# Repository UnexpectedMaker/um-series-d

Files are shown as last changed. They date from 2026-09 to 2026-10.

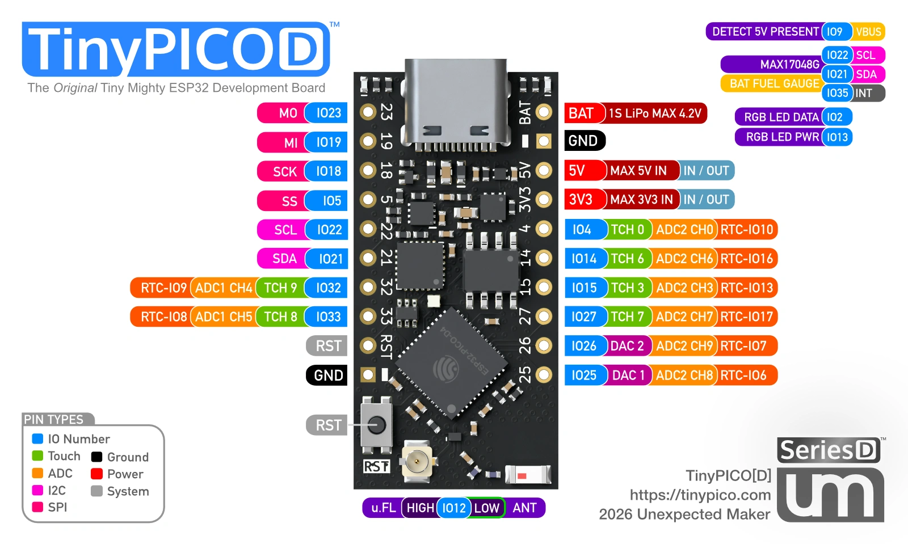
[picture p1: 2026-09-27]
pinout_cards/TinyPICOD_pinout.webp

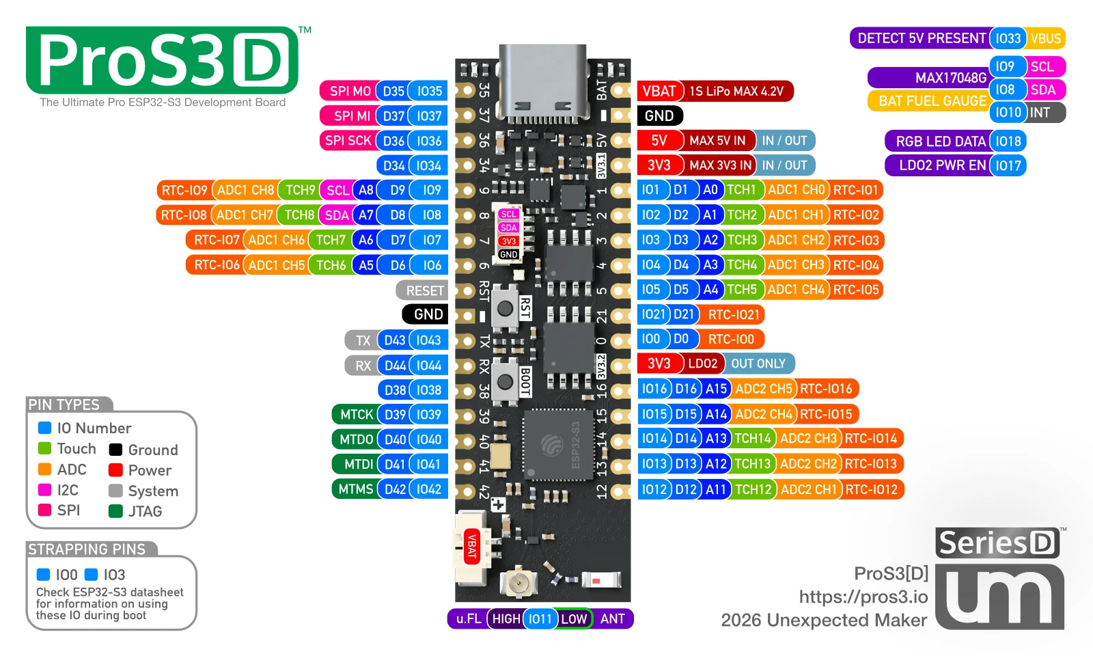
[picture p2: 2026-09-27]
pinout_cards/ProS3D_pinout.webp

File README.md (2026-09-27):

# Unexpected Maker - Series[D]



Assorted files for my Series[D] development boards - ESP32-S3, ESP32-PICO-D4 and ESP32-C6.













You can find out more about my boards at https://unexpectedmaker.com#series-d

# Contents
In this repo you'll find the following items:

## 3D Models
3D STEP files for each of the TinyS3[D], ProS3[D], FeatherS3[D], EdgeS3[D], TinyPICO[D] and TinyC6[D] boards

You'll also find a STEP file for the EdgeS3[D] Reference Carrier board and a STEP for the M.2 connector footprint with the EdgeS3[D] inserted to help line things up.

## Schematics
PDF Schematics for each of the TinyS3[D], ProS3[D], FeatherS3[D], EdgeS3[D], TinyPICO[D] and TinyC6[D] boards.

## Code
Helper libraries, examples and shipping files for Arduino, ESP-IDF, MicroPython and CircuitPython - see the [code folder](code/) for details.

## KiCAD (v9)
Symbol and Footprint for EdgeS3[D] and a project folder for the EdgeS3[D] Reference Carrier PCB.

## Pin Reference Cards
Hi-res pinout reference cards for each of the TinyS3[D], ProS3[D], FeatherS3[D], EdgeS3[D], TinyPICO[D] and TinyC6[D] boards

# Support Unexpected Maker
I love designing, making, and releasing projects and products that empower others to learn and build amazing things! I do it because I believe it’s important to share knowledge and give back to the community as many have done before me. It helps us all learn and grow.

Please consider supporting me by buying some of my products from:

https://unexpectedmaker.com/shop

Or by buying one of my products on tindie or Lectronz:

https://lectronz.com/stores/unexpectedmaker

Or by becoming a Patron:

https://www.patreon.com/unexpectedmaker

## Unexpected Maker
http://youtube.com/c/unexpectedmaker

http://twitter.com/unexpectedmaker

https://discord.gg/xAHpApP

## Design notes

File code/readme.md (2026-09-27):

# Code - Unexpected Maker - Series[D] Boards 
Code examples, shipping files and helper libraries for Series[D] boards - TinyS3[D], ProS3[D], FeatherS3[D], EdgeS3[D], TinyPICO[D] and TinyC6[D].

Currently includes:

## Arduino
Check the [arduino folder](arduino/) for a link to the Series[D] Helper library and example code for the Arduino IDE, to be installed via the library manager. The helper library supports all Series[D] boards, including TinyPICO[D] and TinyC6[D].

## ESP-IDF
The [esp-idf folder](esp-idf/) contains the `um_seriesd` helper component and an example project, for all Series[D] boards. Requires ESP-IDF v5.3 or later.

Set the target for your board (`esp32s3` for TinyS3[D], ProS3[D], FeatherS3[D] and EdgeS3[D], `esp32` for TinyPICO[D] and `esp32c6` for TinyC6[D]) with `idf.py set-target`, then select your board under `UM Series[D] Helper` in `idf.py menuconfig`.

On the TinyC6[D] the RF switch is on the FXL6408 IO expander (XIO0). `um_begin()` sets up the I2C bus and IO expander, and the `um_iox_*` functions give you access to the other IO expander pins.

## MicroPython
Series[D] support for all Series[D] boards is coming to MicroPython as new board variants - the PR has been submitted but not merged yet.

Until then, TinyS3[D], ProS3[D] and FeatherS3[D] can use the original TinyS3, ProS3 and FeatherS3 builds available at [micropython.org](https://micropython.org/download/?vendor=Unexpected%20Maker).

Helper libraries and example code will be available soon.

## CircuitPython
Shipping files include the CircuitPython helper library and `code.py` for each board, plus a `lib` folder populated with the requirements for the `Adafruit MAX17048` Battery FG IC library.

Shipping files are available for TinyS3[D], ProS3[D], FeatherS3[D], EdgeS3[D], TinyPICO[D] and TinyC6[D]. The TinyC6[D] and EdgeS3[D] `lib` folders also include `fxl6408.py` for their IO expander (on the TinyC6[D] the RF switch is on XIO0, on the EdgeS3[D] XIO0-XIO7 are available as `edges3d.io_expander`), and the TinyPICO[D] `lib` folder includes `neopixel`, as the TinyPICO build doesn't have it built in.

CircuitPython support for EdgeS3[D] (that the EdgeS3[D] ships with) has been PR'd and merged into the CircuitPython repo.

There are no Series[D] board specific CircuitPython builds for TinyS3[D], ProS3[D], FeatherS3[D], TinyPICO[D] and TinyC6[D] - They use their original non Series[D] board CircuitPython builds.

Due to this, not every IO used on a Series[D] board is available in the `board` import, but all IO can be accessed using `microcontroller.pin`, for example, to access IO11 on the ProS3 build running on the ProS3[D], you use the following syntax:

``` python
# Setup the RF switch pin
ant_selection = DigitalInOut(microcontroller.pin.GPIO11)
ant_selection.direction = Direction.OUTPUT
```

## PlatformIO
The Arduino helper library can also be used with PlatformIO, see the platformio platform information at https://unexpectedmaker.com/develop.php?platform=platformio#platformio-setup

You can find out more about my Series[D] boards at https://unexpectedmaker.com#series-d

Please refer to the included license.

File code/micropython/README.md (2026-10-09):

# UM Series[D] MicroPython firmware - 2026-10-05

Series[D] support for MicroPython is current in a PR waiting for merge and inclusion in the next MicroPython release, so while we wait for that, I have provided firmware here built against IDF5.5.5 and the last MP main ranch as at October 5, 2026

Each `.bin` is the full merged image (bootloader + partition table + app).
Replace `PORT` with your serial port, e.g. `/dev/cu.usbmodem101`.

Erase first, then write.
Instrucitons below use esptool v5.

## ESP32-S3 boards (offset 0x0)

Download mode: hold BOOT, press and release RESET, release BOOT.

### TinyS3[D]
    esptool --chip  esp32s3 --port PORT erase-flash
    esptool --chip  esp32s3 --port PORT write-flash 0x0 UM_TINYS3D.bin

### ProS3[D]
    esptool --chip  esp32s3 --port PORT erase-flash
    esptool --chip  esp32s3 --port PORT write-flash 0x0 UM_PROS3D.bin

### FeatherS3[D]
    esptool --chip  esp32s3 --port PORT erase-flash
    esptool --chip  esp32s3 --port PORT write-flash 0x0 UM_FEATHERS3D.bin

### EdgeS3[D]
    esptool --chip  esp32s3 --port PORT erase-flash
    esptool --chip  esp32s3 --port PORT write-flash 0x0 UM_EDGES3D.bin

## ESP32-C6 boards (offset 0x0)

Download mode: hold BOOT while connecting USB.
These boards stay in the bootloader after flashing - press RESET to start.

### TinyC6[D]
    esptool --chip esp32c6 --port PORT  erase-flash
    esptool --chip esp32c6 --port PORT  write-flash 0x0 UM_TINYC6D.bin

## ESP32 boards (offset 0x1000)

### TinyPICO[D]
    esptool --chip esp32 --port PORT erase-flash
    esptool --chip esp32 --port PORT write-flash 0x0x1000 UM_TINYPICOD.bin

## Examples

The `examples` folder has a `main.py` for each Series[D] board. Each one uses the board's helper module (`tinys3d`, `pros3d`, `feathers3d`, `edges3d`, `tinyc6d` or `tinypicod`), which is built into the firmware above.

TinyC6[D] and TinyPICO[D] ship with MicroPython, so their `main.py` is the shipping code. TinyS3[D], ProS3[D], FeatherS3[D] and EdgeS3[D] ship with CircuitPython, so theirs are examples for when you put MicroPython on them.

Every example prints a hello, memory and flash info, and what's on the I2C bus, then cycles the RGB LED through a rainbow and prints the battery voltage and charge every 2 seconds. The TinyC6[D] and EdgeS3[D] also print the FXL6408 IO expander device ID.

The EdgeS3[D] has no RGB LED, so its example does the same without the rainbow.

To use one, copy it to your board as `main.py` and it will run at boot, for example:

`mpremote cp main.py :main.py`

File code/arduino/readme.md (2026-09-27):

# Unexpected Maker Series[D] Arduino Helper Library

This is the [helper library](https://github.com/UnexpectedMaker/seriesd_arduino_helper) for all the Unexpected Maker [Series[D] boards](https://unexpectedmaker.com/#series-d) - TinyS3[D], ProS3[D], FeatherS3[D], EdgeS3[D], TinyPICO[D] and TinyC6[D]. It can be used in the Arduino IDE or PlatformIO.

Examples can be found in the [examples directory](https://github.com/UnexpectedMaker/seriesd_arduino_helper/tree/main/examples), these can also be loaded from the examples menu in the Arduino IDE.

Examples include switching antenna output, reading the battery, controlling the RGB LED (if one is present on the board) and reading the light sensor (FeatherS3[D]).

## Selecting your Series[D] board

Apart from the EdgeS3[D], the Series[D] boards don't have their own [D] board listing in the Arduino boards list. Select the original board instead:

| Series[D] board | Board to select |
|---|---|
| TinyS3[D] | UM TinyS3 |
| ProS3[D] | UM PROS3 |
| FeatherS3[D] | UM FeatherS3 |
| TinyPICO[D] | UM TinyPICO |
| TinyC6[D] | UM TinyC6 |
| EdgeS3[D] | UM EdgeS3[D] |

## Installation

Please download the library called `UM SeriesD Helper` via the Arduino Library Manager.

## List of functions

```c++

// Initializes all UM Series[D] board peripherals
void begin();

// Set LDO2 on or off
// Only available on the ProS3[D] and FeatherS3[D] 
void setLDO2Power(bool on);

// Set RGB LED power on or off (On ProS3[D] and FeatherS3[D] it sets LDO2 on)
// Not available on the EdgeS3[D] 
void setPixelPower(bool on);

// Set RGB LED color
// Not available on the EdgeS3[D] 
void setPixelColor(uint8_t r, uint8_t g, uint8_t b);
void setPixelColor(uint32_t rgb);

// Set RGB LED brightness
// Not available on the EdgeS3[D] 
void setPixelBrightness(uint8_t brightness);

// Pack r,g,b (0-255) into a 32bit rgb color
static uint32_t color(uint8_t r, uint8_t g, uint8_t b);

// Convert a color wheel angle (0-255) to a 32bit rgb color
static uint32_t colorWheel(uint8_t pos);

// Set the blue LED on or off
// Only available on the FeatherS3[D]
void setBlueLED(bool on);

// Get the light sensor in volts (0-3.3)
// Only available on the FeatherS3[D]
float getLightSensorVoltage();

// Toggle the blue LED
// Only available on the FeatherS3[D]
void toggleBlueLED();

// Get the battery voltage in volts
// This function gets the voltage from the MAX17048
float getBatteryVoltage();

// Detect if VBUS (USB power) is present
// Not available on the EdgeS3[D] 
bool getVbusPresent();

// Set the RF Switch to external antenna
// On the TinyC6[D] the RF Switch is on the FXL6408 IO expander (XIO0)
void setAntennaExternal(bool state);

// FXL6408 IO expander (uses the TwoWire passed to FG_setup, or Wire if begin() is called first)
// Only available on the TinyC6[D]
bool IOX_begin();
void IOX_pinMode(uint8_t pin, uint8_t mode);
void IOX_digitalWrite(uint8_t pin, bool state);
bool IOX_digitalRead(uint8_t pin);
```

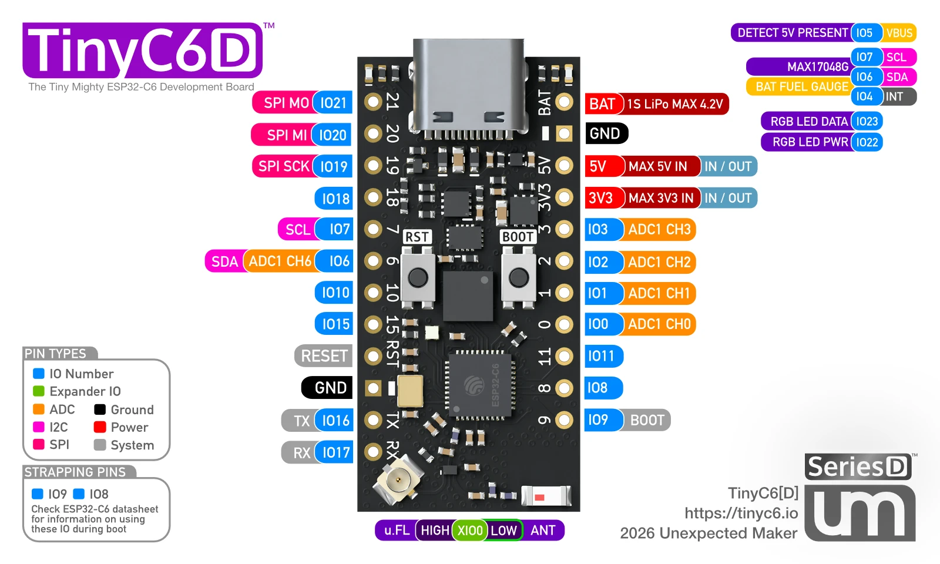
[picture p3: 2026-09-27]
pinout_cards/TinyC6D_pinout.webp

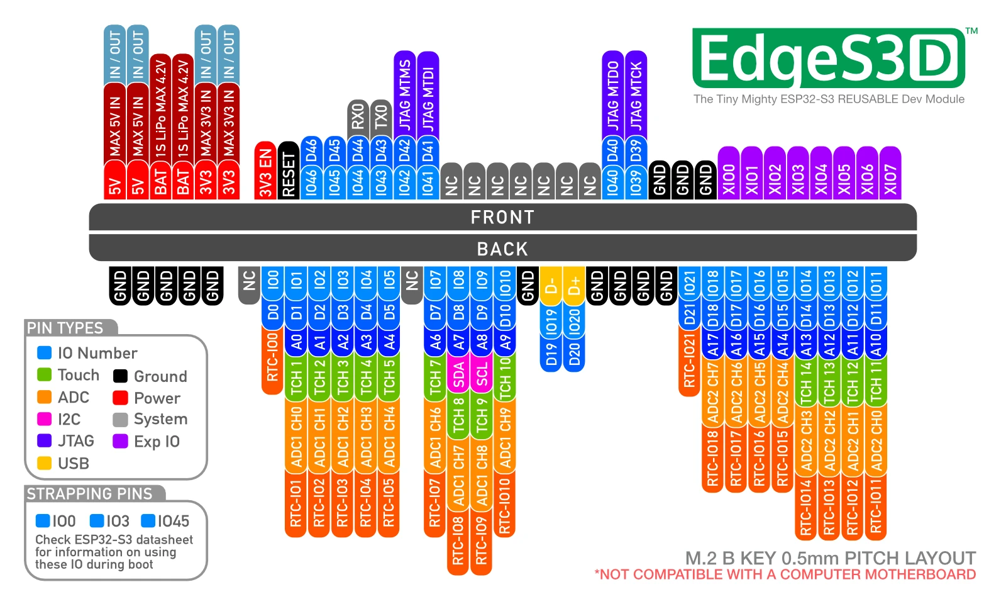
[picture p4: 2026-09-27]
pinout_cards/EdgeS3D_pinout.webp

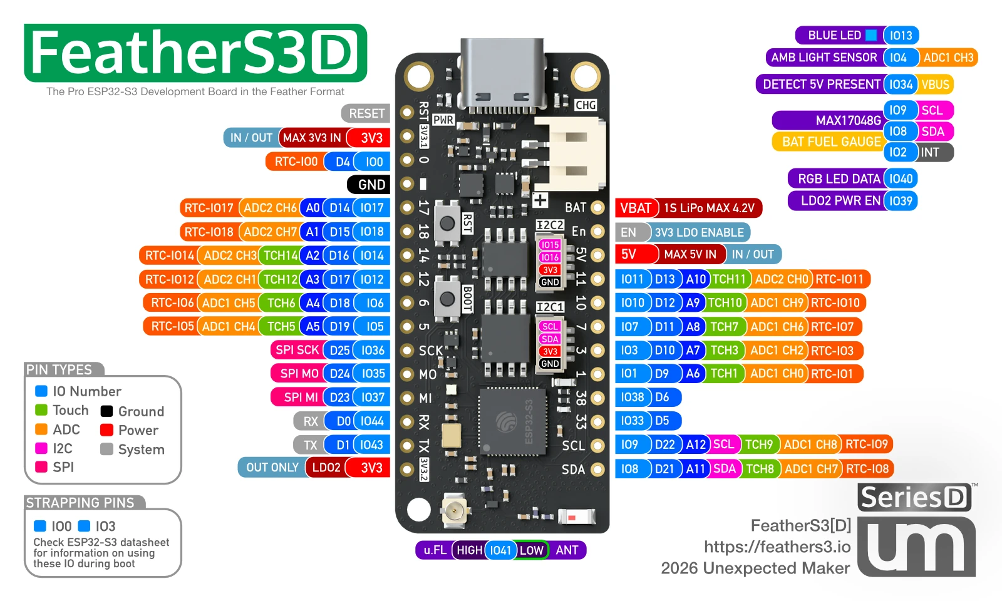
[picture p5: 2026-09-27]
pinout_cards/FeatherS3D_pinout.webp

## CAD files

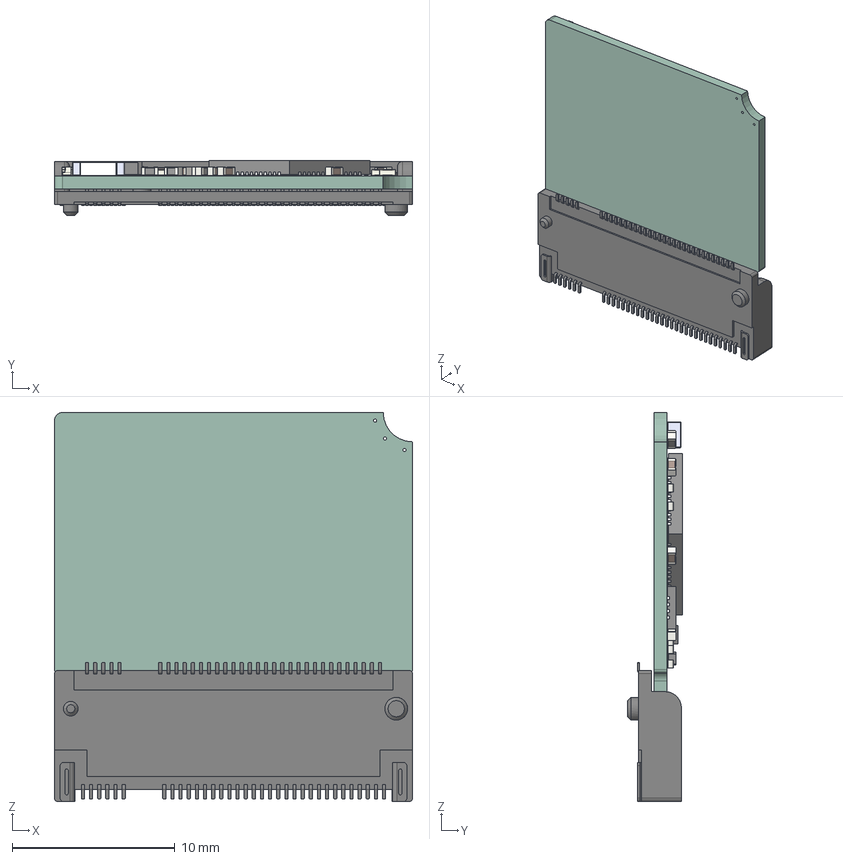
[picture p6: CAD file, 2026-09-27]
3d models/EdgeS3D_plus_Mdot2.step
22.0 x 3.35 x 23.9 mm
C_0402_1005Metric_16 x 16
L_0402_1005Metric_3 x 3
R_0402_1005Metric_14 x 14
TESD5V0L1UC RJG x 3
LED_0402_1005Metric_2 x 2
ESD7C5.0DT5G
NCP160AMX280TBG
FXL4TD245UMX
D_SOD_523
2450AT18B100E
TDFN_6_1EP_25x25mm_P065mm_EP13x2mm
MAX17048G+T10
ESP32-S2
EdgeS3_R1_PCB
MDT275B03001--3DModel-STEP-533217

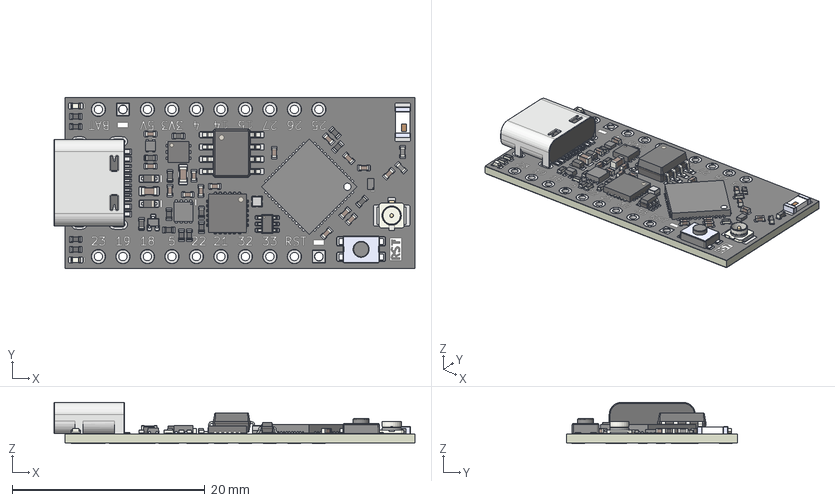
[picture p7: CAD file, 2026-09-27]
3d models/TinyPICOD.step
37.4 x 17.8 x 4.28 mm
BGS12WN6E6327XTSA1
R_0402_1005Metric x 17
C_0402_1005Metric x 15
SSOP-8_3.9x5.05mm_P1.27mm
D_SOD_523 x 2
KMR221GLFS--3DModel-STEP-56544 v3
RGB_LED_1010
2450AT18B100E
C_0603_1608Metric x 2
SOT-363_SC-70-6
U.FL_Hirose_U.FL-R-SMT-1_Vertical
NCP160AMX280TBG
HRO USB-C col 3
LED_0402_1005Metric x 2
TDFN_6_1EP_25x25mm_P065mm_EP13x2mm
ESD7C5.0DT5G
L_0402_1005Metric x 2
ESP32-S2
MAX17048G+T10
QFN-24-1EP_4x4mm_P0.5mm_EP2.7x2.7mm
TinyPICOD_P1-unsaved-export-sBRmF5_copper
TinyPICOD_P1-unsaved-export-sBRmF5_pad
TinyPICOD_P1-unsaved-export-sBRmF5_via
TinyPICOD_P1-unsaved-export-sBRmF5_silkscreen x 2
TinyPICOD_P1-unsaved-export-sBRmF5_soldermask x 2
TinyPICOD_P1-unsaved-export-sBRmF5_PCB

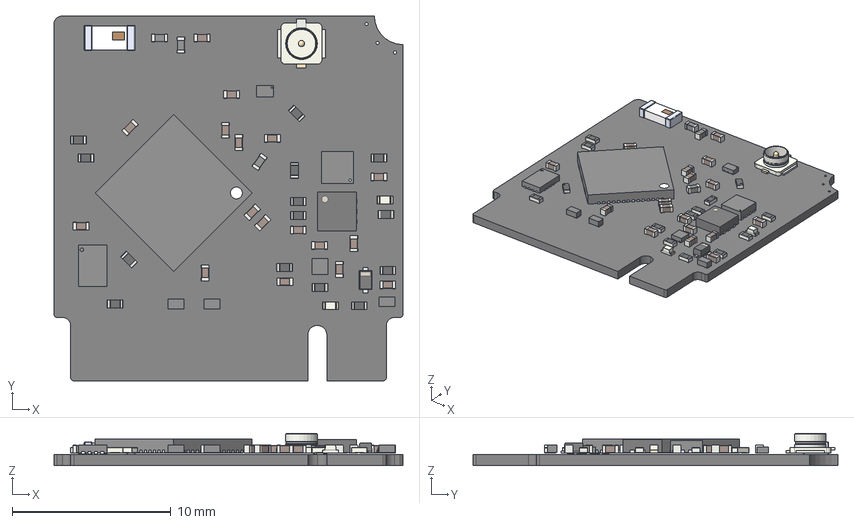
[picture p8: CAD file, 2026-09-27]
3d models/EdgeS3D.step
22.0 x 23.0 x 2.05 mm
C_0402_1005Metric x 17
U.FL_Hirose_U.FL-R-SMT-1_Vertical
BGS12WN6E6327XTSA1
L_0402_1005Metric x 3
R_0402_1005Metric x 14
TVS_DFN1006 x 3
LED_0402_1005Metric x 2
NCP170AMX170TCG
FXL6408UMX
D_SOD-523
2450AT18B100E--3DModel-STEP-269445
TDFN-6-1EP_2.5x2.5mm_P0.65mm_EP1.3x2mm
MAX17048G-T10
ESP32_S2--3DModel-STEP-1
EdgeS3_Dual_R1_PCB

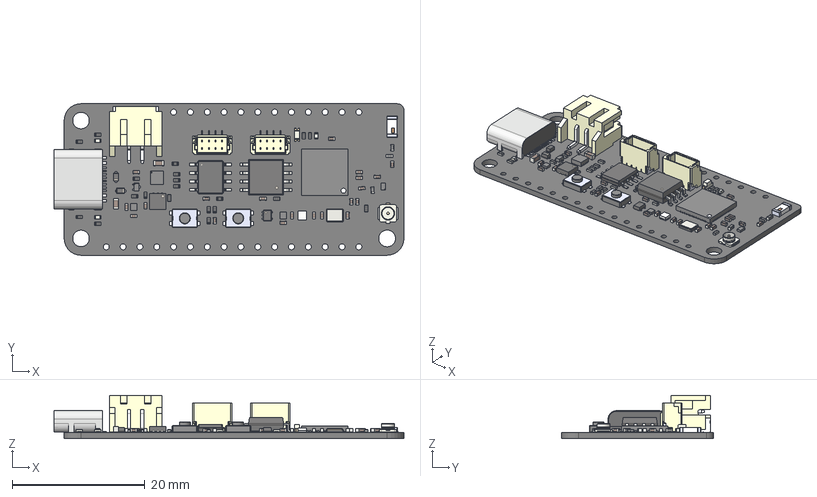
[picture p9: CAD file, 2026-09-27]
3d models/FeatherS3D.step
52.8 x 22.9 x 6.50 mm
R_0402_1005Metric x 20
2450AT18B100E--3DModel-STEP-269445
D_SOD-523 x 2
LED_0402_1005Metric x 3
C_0402_1005Metric x 20
SOT-723
KMR221GLFS--3DModel-STEP-56544 v3 x 2
HIRO-USB-C Fixed Position
LED_0805_2012Metric_Castellated
ESP32_S2--3DModel-STEP-1
L_0402_1005Metric x 3
SSOP-8_3.9x5.05mm_P1.27mm
C_0603_1608Metric x 2
U.FL_Hirose_U.FL-R-SMT-1_Vertical
SOIC-8_5.3x5.3mm_P1.27mm
MAX17048G-T10
BGS12WN6E6327XTSA1
TDFN-6-1EP_2.5x2.5mm_P0.65mm_EP1.3x2mm
NCP170AMX170TCG x 2
JST_SH_4pin_Vert x 2
JST_PH_2pion_Horiz
Crystal_SMD_3225-4Pin_3.2x2.5mm_HandSoldering
SOT-553
FeatherS3D_P1_PCB

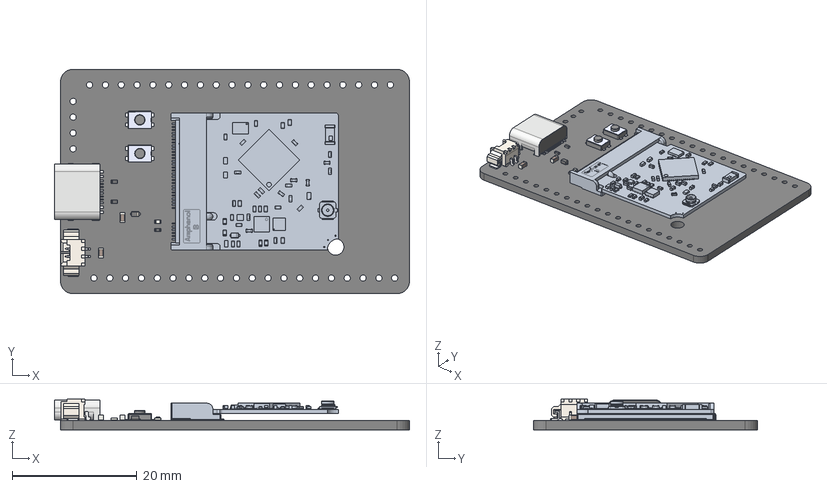
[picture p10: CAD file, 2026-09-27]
3d models/EdgeS3D_Carrier_P1.step
57.0 x 36.0 x 4.95 mm
D_SOD-523
KMR221GLFS--3DModel-STEP-56544 v3 x 2
R_0402_1005Metric x 3
LED_0402_1005Metric
HIRO-USB-C Fixed Position
C_0603_1608Metric x 2
EdgeS3D_Carrier_P1 1.11.1
EdgeS3D_Carrier_P1 1.11.2
PICOBLADE Col v3
EdgeS3D_Carrier_P1_PCB

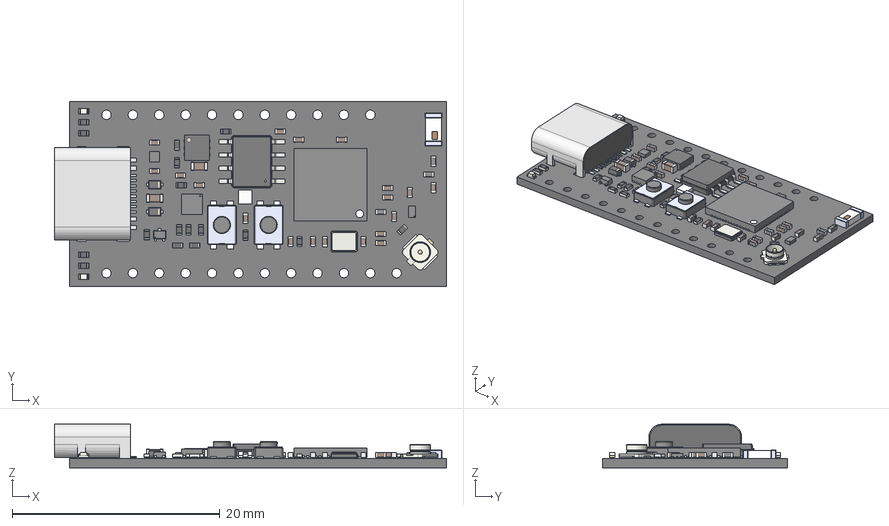
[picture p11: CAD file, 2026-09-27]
3d models/TinyS3D.step
37.7 x 17.8 x 4.21 mm
R_0402_1005Metric x 17
C_0402_1005Metric x 19
TDFN-6-1EP_2.5x2.5mm_P0.65mm_EP1.3x2mm
L_0402_1005Metric x 3
KMR221GLFS--3DModel-STEP-56544 v3 x 2
U.FL_Hirose_U.FL-R-SMT-1_Vertical
BGS12WN6E6327XTSA1
LED_0402_1005Metric x 2
MAX17048G-T10
SOT-723
NCP170AMX170TCG
D_SOD-523 x 2
SSOP-8_3.9x5.05mm_P1.27mm
2450AT18B100E--3DModel-STEP-269445
Crystal_SMD_3225-4Pin_3.2x2.5mm_HandSoldering
C_0603_1608Metric x 2
ESP32_S2--3DModel-STEP-1
HIRO-USB-C Fixed Position
TinyS3D_P1_PCB

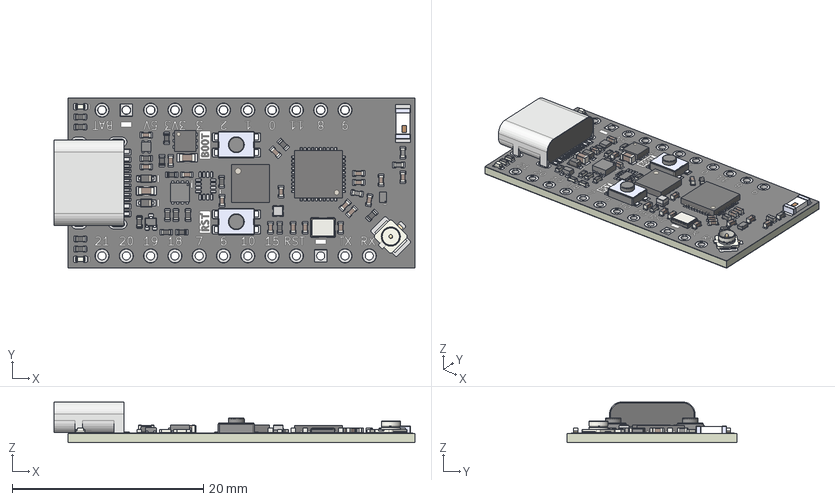
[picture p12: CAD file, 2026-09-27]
3d models/TinyC6D.step
37.7 x 17.8 x 4.28 mm
C_0402_1005Metric x 18
TDFN_6_1EP_25x25mm_P065mm_EP13x2mm
KMR221GLFS--3DModel-STEP-56544 v3 x 2
R_0402_1005Metric x 18
LED_0402_1005Metric x 2
MAX17048G+T10
L_0402_1005Metric x 3
BGS12WN6E6327XTSA1
2450AT18B100E
RGB_LED_1010
ESD7C5.0DT5G
NCP160AMX280TBG
D_SOD_523 x 2
WSON8_4x4mm_Pitch08mm
U.FL_Hirose_U.FL-R-SMT-1_Vertical
Crystal_SMD_3225-4Pin_3.2x2.5mm_HandSoldering
C_0603_1608Metric x 2
QFN-40-1EP_5x5mm_Pitch0.4mm
HRO USB-C col 3 v9
TinyC6D_P1-unsaved-export-s41lxL_copper
TinyC6D_P1-unsaved-export-s41lxL_pad
TinyC6D_P1-unsaved-export-s41lxL_via
TinyC6D_P1-unsaved-export-s41lxL_silkscreen x 2
TinyC6D_P1-unsaved-export-s41lxL_soldermask x 2
TinyC6D_P1-unsaved-export-s41lxL_PCB

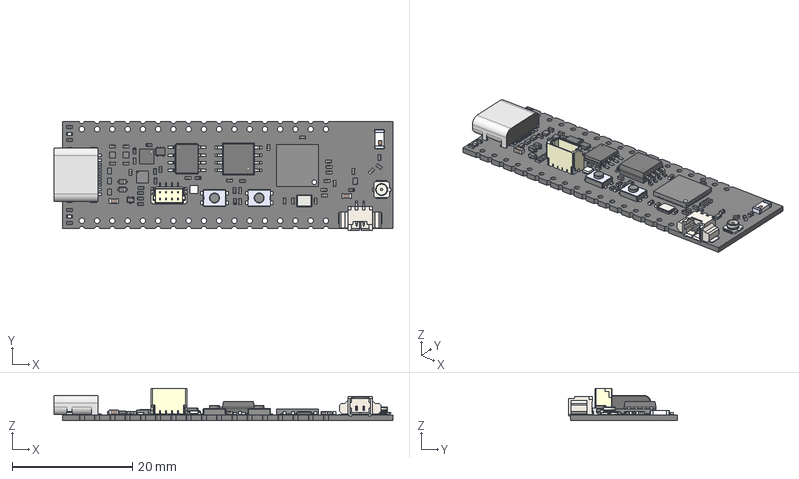
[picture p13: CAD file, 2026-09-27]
3d models/ProS3D.step
56.4 x 18.1 x 5.35 mm
R_0402_1005Metric x 18
MAX17048G-T10
PICOBLADE Col v3
C_0402_1005Metric x 23
SOT-665
SOT-723
NCP170AMX170TCG x 2
C_0603_1608Metric x 2
ESP32_S2--3DModel-STEP-1
2450AT18B100E--3DModel-STEP-269445
KMR221GLFS--3DModel-STEP-56544 v3 x 2
Crystal_SMD_3225-4Pin_3.2x2.5mm_HandSoldering
D_SOD-523 x 2
TVS_DFN1006 x 3
L_0402_1005Metric x 3
U.FL_Hirose_U.FL-R-SMT-1_Vertical
LED_0402_1005Metric x 2
BGS12WN6E6327XTSA1
SSOP-8_3.9x5.05mm_P1.27mm
HIRO-USB-C Fixed Position
SOIC-8_5.3x5.3mm_P1.27mm
TDFN-6-1EP_2.5x2.5mm_P0.65mm_EP1.3x2mm
JST_SH_4pin_Vert
ProS3D_P1_Temp_For_Model_PCB

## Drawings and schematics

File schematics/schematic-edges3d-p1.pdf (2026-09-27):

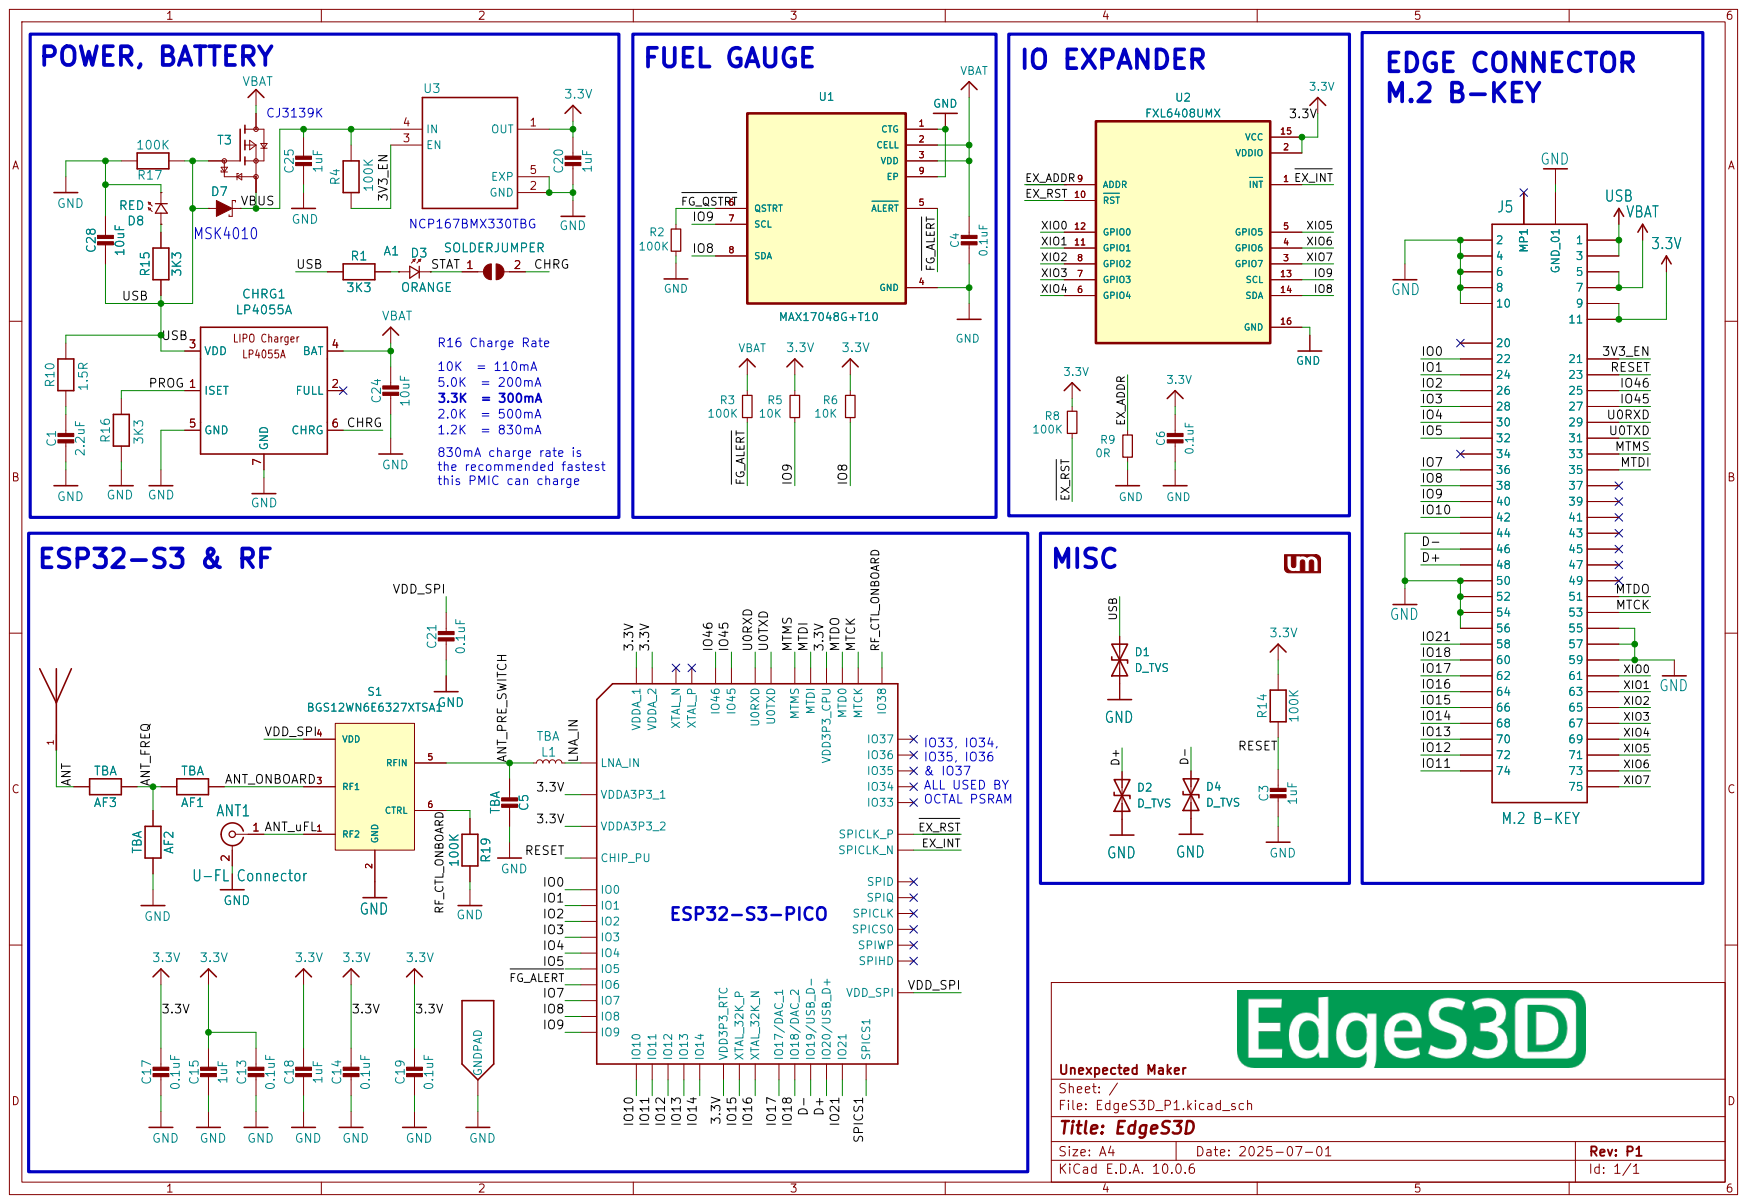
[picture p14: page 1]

R16 Charge Rate POWER, BATTERY

the recommended fastest
this PMIC can charge

ALL USED BY OCTAL PSRAM

Size: A4 | Rev: P1
KiCad E.D.A. 10.0.6 | Id: 1/1

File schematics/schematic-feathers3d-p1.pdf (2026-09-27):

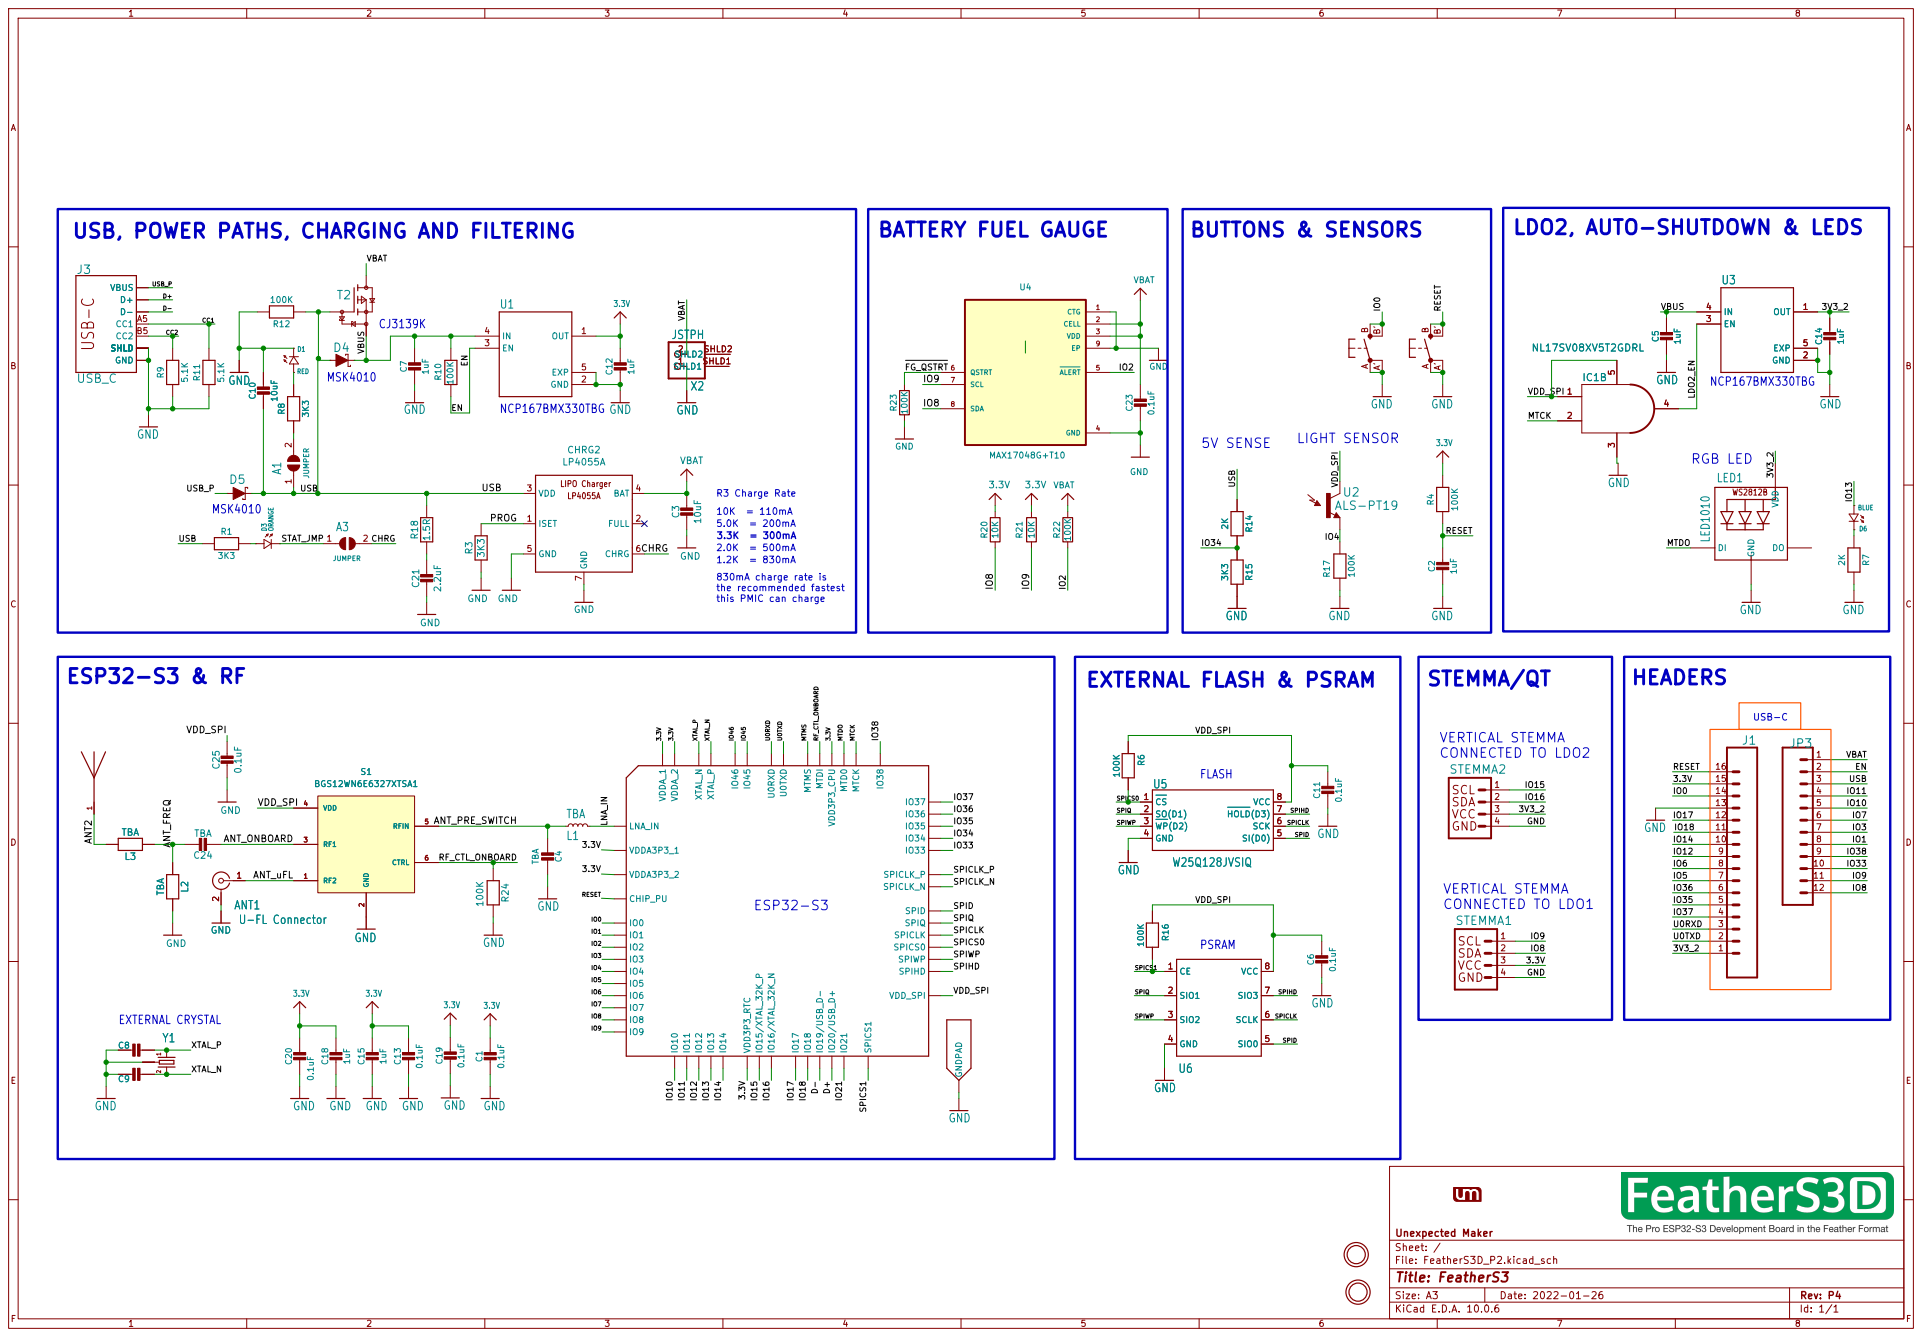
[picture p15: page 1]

USB, POWER PATHS, CHARGING AND FILTERING

1 C3 10uF GND GND GND 2KR7 WS2812B DI DO GND VDD

830mA charge rate is
the recommended fastest
this PMIC can charge

Size: A3 | Rev: P4 | F Date: 2022-01-26
KiCad E.D.A. 10.0.6 | Id: 1/1

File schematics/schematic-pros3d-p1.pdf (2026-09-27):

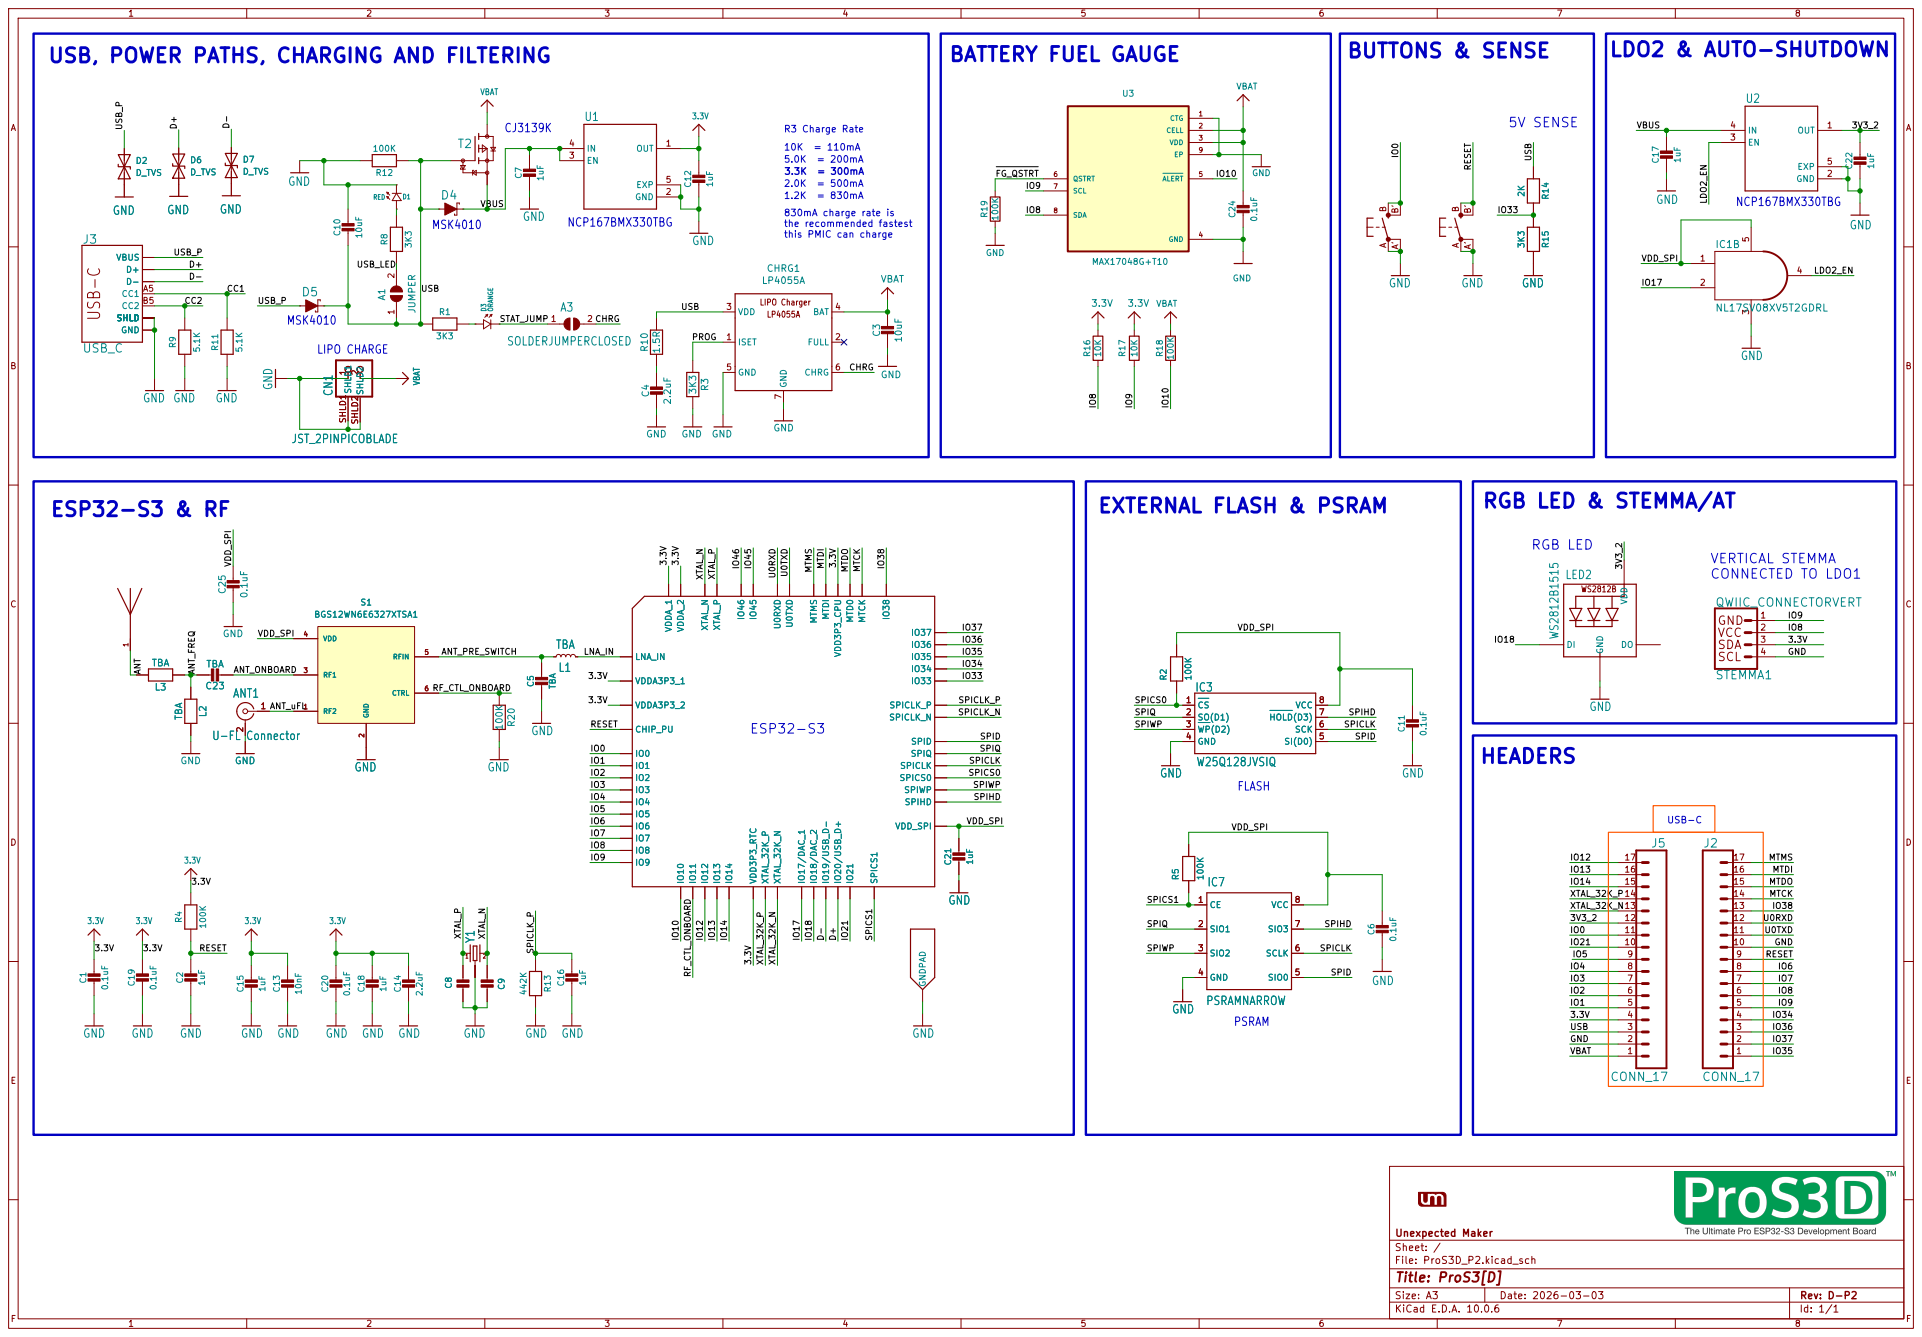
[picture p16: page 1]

USB, POWER PATHS, CHARGING AND FILTERING

this PMIC can charge 2.0K = 500mA 5.0K = 200mA 1.2K = 830mA NCP167BMX330TBG

RGB LED & STEMMA/AT

IO38 MTCK MTMS MTDI MTDO

Size: A3 | Rev: D-P2 | F Date: 2026-03-03
KiCad E.D.A. 10.0.6 | Id: 1/1

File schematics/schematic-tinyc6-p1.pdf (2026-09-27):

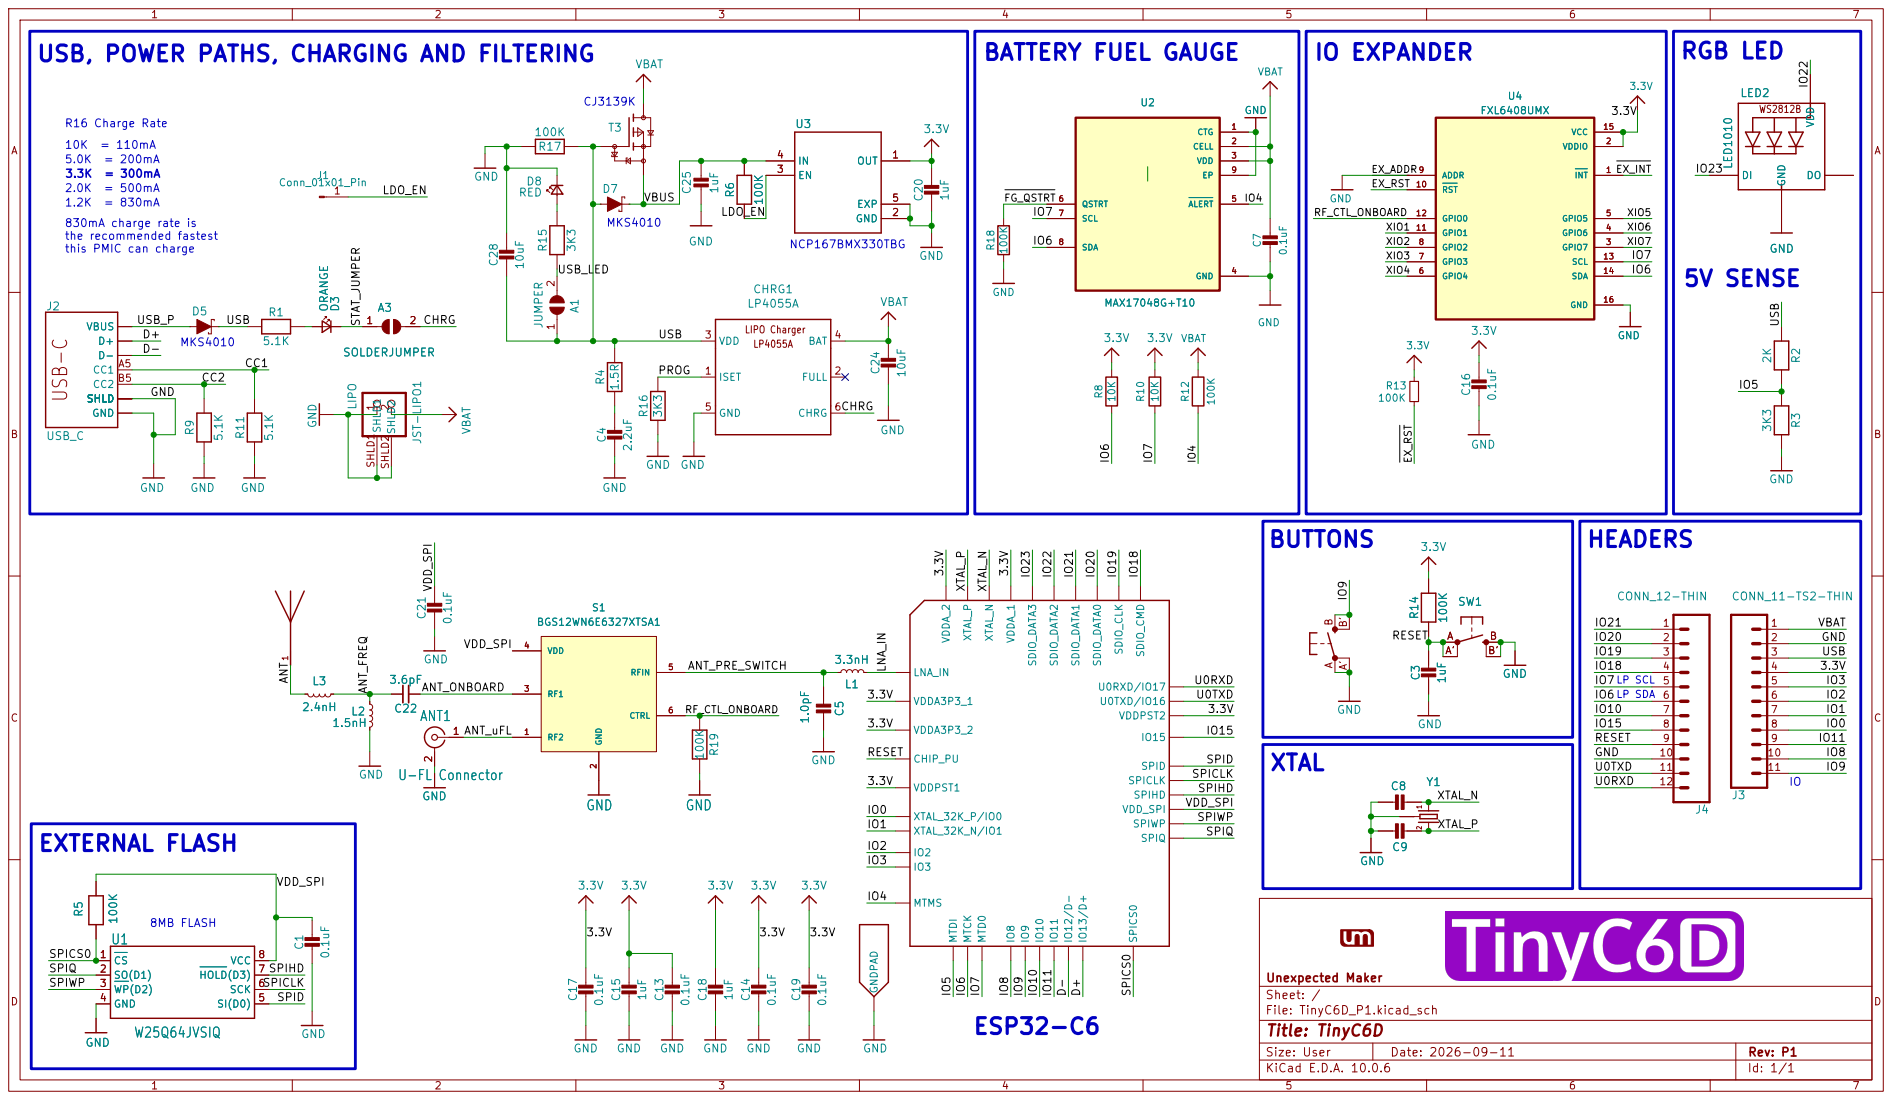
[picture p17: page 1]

USB, POWER PATHS, CHARGING AND FILTERING

this PMIC can charge 5.0K = 200mA

Size: User | Rev: P1
KiCad E.D.A. 10.0.6 | Id: 1/1

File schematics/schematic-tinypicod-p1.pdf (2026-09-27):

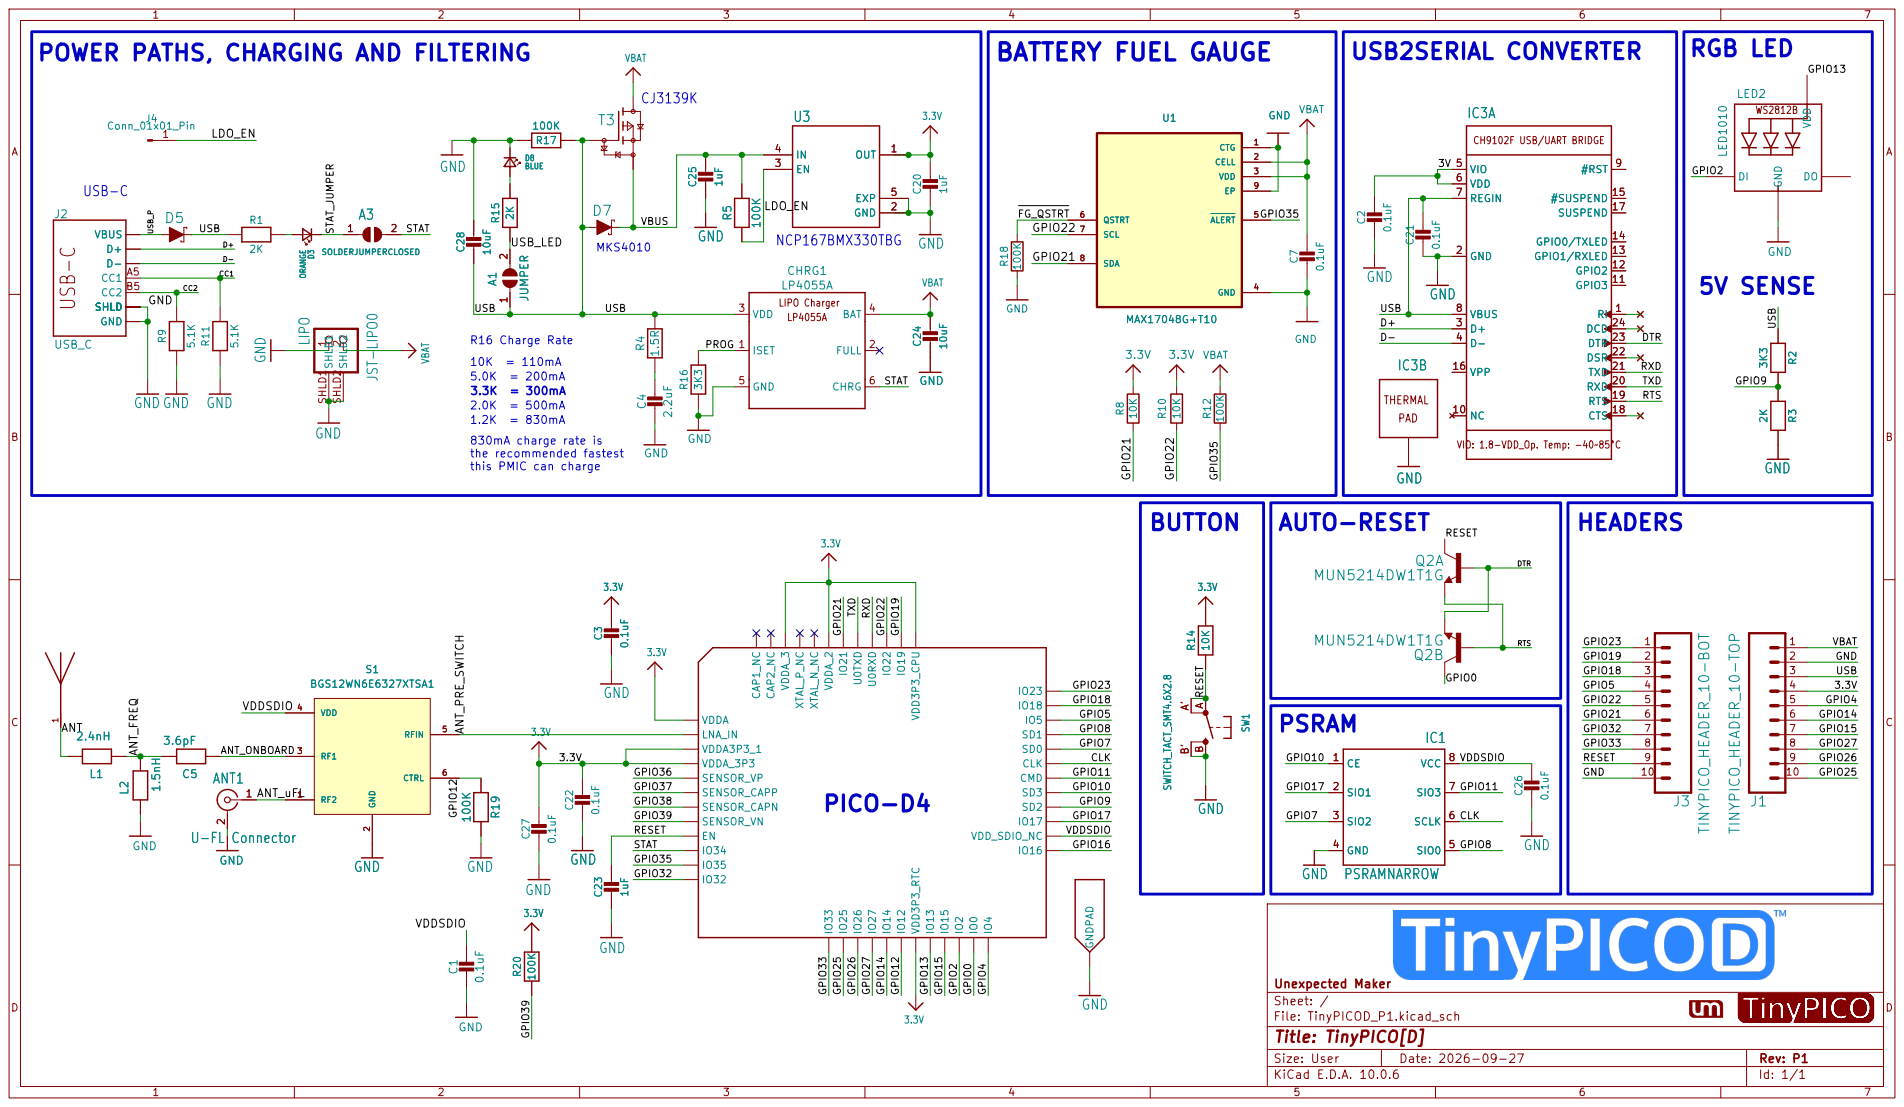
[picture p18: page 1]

POWER PATHS, CHARGING AND FILTERING

SUSPEND 17 CTS 18 RTS 19 RXD 20 TXD 21 DSR 22 DTR 23 DCD 24

SUSPEND 17 CTS 18 RTS 19 RXD 20 TXD 21 DSR 22 DTR 23 DCD 24 GND

Size: User | Rev: P1
KiCad E.D.A. 10.0.6 | Id: 1/1

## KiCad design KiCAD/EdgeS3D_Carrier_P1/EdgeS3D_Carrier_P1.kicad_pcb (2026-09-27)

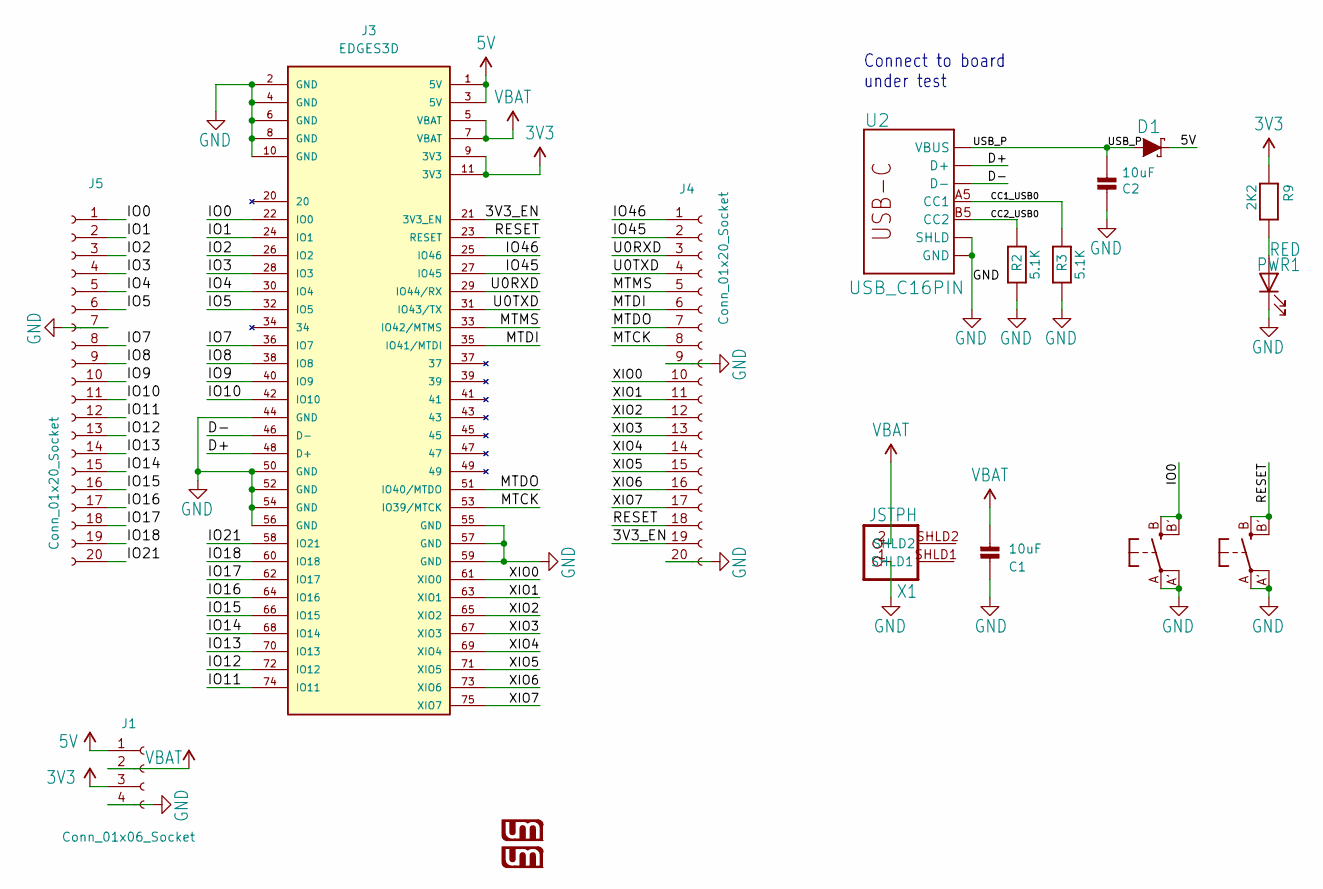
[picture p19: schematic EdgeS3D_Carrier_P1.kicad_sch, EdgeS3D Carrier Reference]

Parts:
C1, C2: 10uF; C_0603_1608Metric
D1: DIODE-SCHOTTKYWIDE; SOD-523-MSK4010
J1: Conn_01x06_Socket; PinHeader_1x04_P2.54mm_Vertical
J3: EDGES3D; AMPHENOL_MDT275B03001; PARTREV 7
J4, J5: Conn_01x20_Socket; PinHeader_1x20_P2.54mm_Vertical
PWR1: RED; LED_0805_2012Metric
R2, R3: 5.1K; R_0402_1005Metric
R9: 2K2; _0805MP
SW1, SW2: KMR2; BTN_KMR2_4.6X2.8
U2: USB_C16PIN; USB-C-16P-LESSPASTE-2-FIxed
U$1, U$2: UM_LOGONEW_SMALL; UM_LOGO_NEW_SMALL
X1: JSTPH; JST-PICOBLADE

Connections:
3V3: J1.3, J3.9 (3V3), J3.11 (3V3), R9.1
5V: D1.C, J1.1, J3.1 (5V), J3.3 (5V)
/3V3_EN: J3.21 (3V3_EN), J4.19
/CC1_USB0: R3.2, U2.A5 (CC1)
/CC2_USB0: R2.2, U2.B5 (CC2)
/D+: J3.48 (D+), U2.A6 (D+), U2.B6 (D+)
/D-: J3.46 (D-), U2.A7 (D-), U2.B7 (D-)
/IO0: J3.22 (IO0), J5.1, SW1.B (S), SW1.B' (S1)
/IO1: J3.24 (IO1), J5.2
/IO2: J3.26 (IO2), J5.3
/IO3: J3.28 (IO3), J5.4
/IO4: J3.30 (IO4), J5.5
/IO5: J3.32 (IO5), J5.6
/IO7: J3.36 (IO7), J5.8
/IO8: J3.38 (IO8), J5.9
/IO9: J3.40 (IO9), J5.10
/IO10: J3.42 (IO10), J5.11
/IO11: J3.74 (IO11), J5.12
/IO12: J3.72 (IO12), J5.13
/IO13: J3.70 (IO13), J5.14
/IO14: J3.68 (IO14), J5.15
/IO15: J3.66 (IO15), J5.16
/IO16: J3.64 (IO16), J5.17
/IO17: J3.62 (IO17), J5.18
/IO18: J3.60 (IO18), J5.19
/IO21: J3.58 (IO21), J5.20
/IO45: J3.27 (IO45), J4.2
/IO46: J3.25 (IO46), J4.1
/MTCK: J3.53 (IO39/MTCK), J4.8
/MTDI: J3.35 (IO41/MTDI), J4.6
/MTDO: J3.51 (IO40/MTDO), J4.7
/MTMS: J3.33 (IO42/MTMS), J4.5
/RESET: J3.23 (RESET), J4.18, SW2.B (S), SW2.B' (S1)
/U0RXD: J3.29 (IO44/RX), J4.3
/U0TXD: J3.31 (IO43/TX), J4.4
/USB_P: C2.2, D1.A, U2.VBUS1 (VBUS), U2.VBUS2 (VBUS)
/XIO0: J3.61 (XIO0), J4.10
/XIO1: J3.63 (XIO1), J4.11
/XIO2: J3.65 (XIO2), J4.12
/XIO3: J3.67 (XIO3), J4.13
/XIO4: J3.69 (XIO4), J4.14
/XIO5: J3.71 (XIO5), J4.15
/XIO6: J3.73 (XIO6), J4.16
/XIO7: J3.75 (XIO7), J4.17
GND: C1.1, C2.1, J1.4, J3.2 (GND), J3.4 (GND), J3.6 (GND), J3.8 (GND), J3.10 (GND), J3.44 (GND), J3.50 (GND), J3.52 (GND), J3.54 (GND), J3.55 (GND), J3.56 (GND), J3.57 (GND), J3.59 (GND), J4.9, J4.20, J5.7, PWR1.1 (K), R2.1, R3.1, SW1.A, SW1.A' (P1), SW2.A, SW2.A' (P1), U2.GND, U2.GND2 (GND), U2.SHLD, U2.SHLD2 (SHLD), U2.SHLD3 (SHLD), U2.SHLD4 (SHLD), U2.SHLD5 (SHLD), U2.SHLD6 (SHLD), U2.SHLD7 (SHLD), U2.SHLD8 (SHLD), X1.1
unnamed: PWR1.2 (A), R9.2
VBAT: C1.2, J1.2, J3.5 (VBAT), J3.7 (VBAT), X1.2

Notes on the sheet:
Connect to board under test

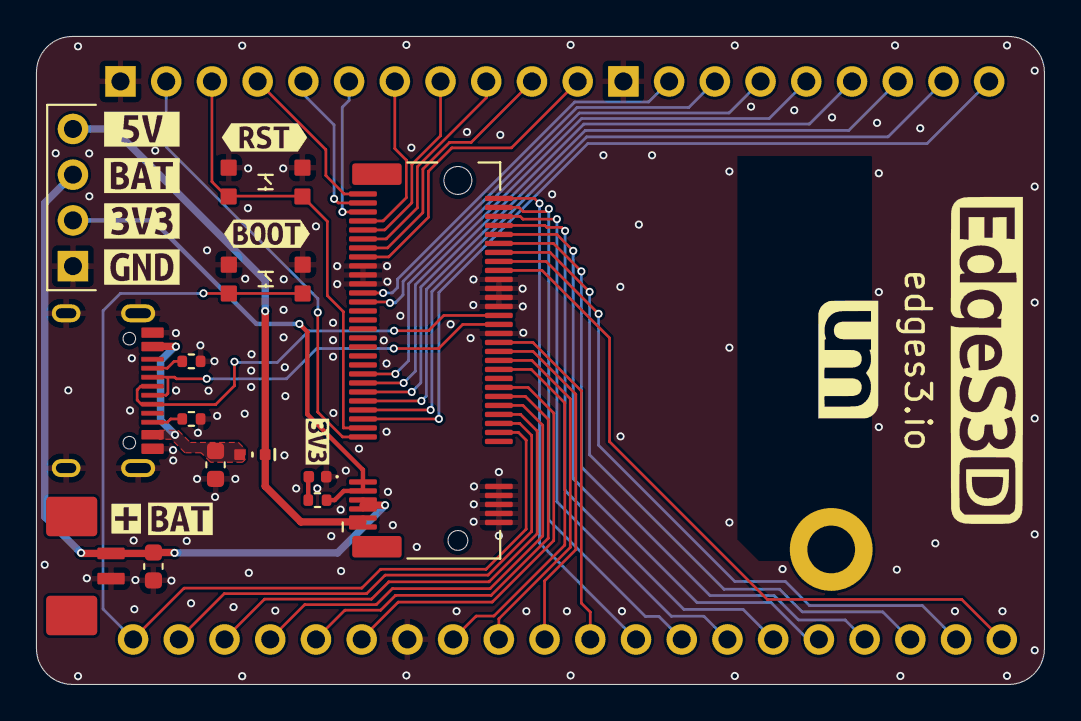
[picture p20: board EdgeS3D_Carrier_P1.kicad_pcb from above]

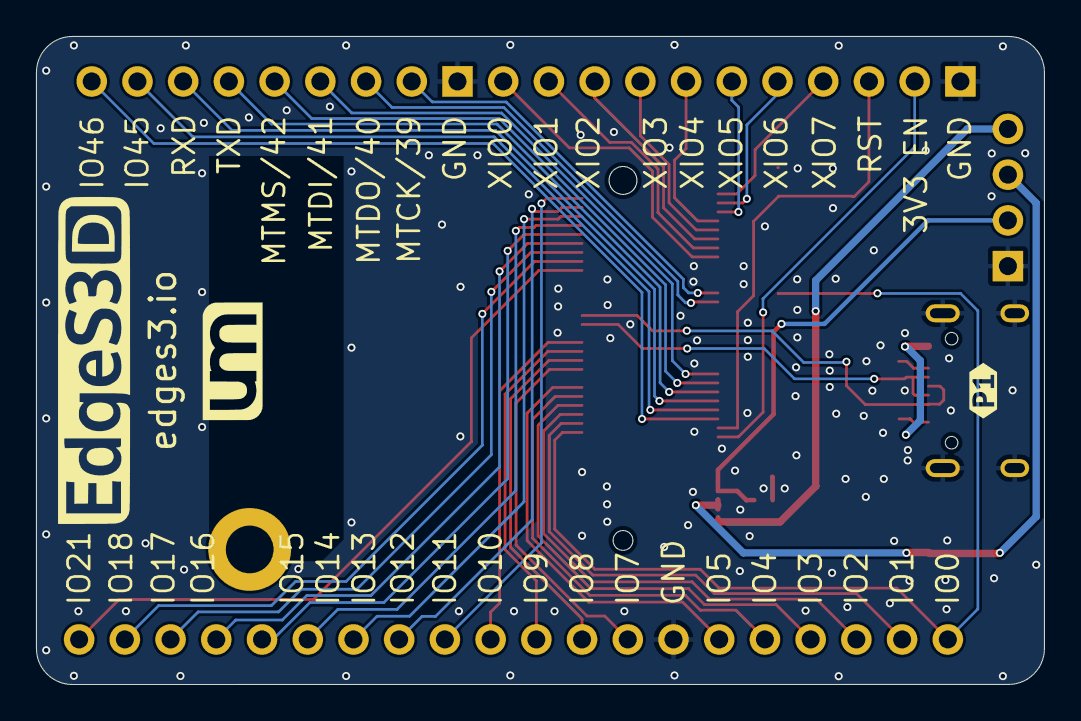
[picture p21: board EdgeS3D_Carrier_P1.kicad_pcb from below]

Board: 2 copper layers, 56.0 x 36.0 mm, 27 parts (2 on the bottom side), 47 nets.

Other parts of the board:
kibuzzard-66BFF55A: G***; kibuzzard-66BFF55A
kibuzzard-66BFF56B: G***; kibuzzard-66BFF56B
kibuzzard-66C05786: G***; kibuzzard-66C05786
kibuzzard-6857AC6A: G***; kibuzzard-6857AC6A
kibuzzard-6857AC7B: G***; kibuzzard-6857AC7B
kibuzzard-6857AC8E: G***; kibuzzard-6857AC8E
kibuzzard-6857AC89: G***; kibuzzard-6857AC89
kibuzzard-6857AD16: G***; kibuzzard-6857AD16
kibuzzard-6857ADA7: G***; kibuzzard-6857ADA7
kibuzzard-664315DB: G***; kibuzzard-664315DB

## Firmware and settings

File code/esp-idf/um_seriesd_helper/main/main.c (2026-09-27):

#include "um_seriesd.h"
#include "um_seriesd_pins.h"
#include "esp_log.h"
#include "freertos/FreeRTOS.h"
#include "freertos/task.h"

void app_main(void)
{
    ESP_ERROR_CHECK(um_begin());
    ESP_LOGI("app", "Board: %s", um_board_name());

    // Pixel demo (setting a color turns the pixel power on)
    um_set_pixel_brightness(32);
    for (int i = 0; i < 255; i += 8)
    {
        um_set_pixel_color_u32(um_color_wheel(i));
        vTaskDelay(pdMS_TO_TICKS(20));
    }
    um_set_pixel_power(false);

    // ALS (FeatherS3[D] only)
    float v = 0.0f;
    if (um_get_light_sensor_voltage(&v) == ESP_OK)
    {
        ESP_LOGI("app", "ALS = %.3f V", v);
    }

    // VBUS
    ESP_LOGI("app", "VBUS: %s", um_get_vbus_present() ? "present" : "not present");

    // Fuel gauge on the board's I2C pins @ 400kHz
    // (on TinyC6[D] um_begin() already set up this bus for the IO expander, so it's reused)
    if (um_fg_setup(0, UM_GPIO_I2C_SDA, UM_GPIO_I2C_SCL, 400000) == ESP_OK)
    {
        float vbatt = 0.0f;
        if (um_fg_get_battery_voltage(&vbatt) == ESP_OK)
            ESP_LOGI("app", "VBAT = %.3f V", vbatt);
        uint8_t ver = 0;
        if (um_fg_get_version(&ver) == ESP_OK)
            ESP_LOGI("app", "MAX17048 version = 0x%02X", ver);
    }

    // RF switch (on the IO expander on TinyC6[D])
    um_set_antenna_external(true);
    vTaskDelay(pdMS_TO_TICKS(300));
    um_set_antenna_external(false);
}

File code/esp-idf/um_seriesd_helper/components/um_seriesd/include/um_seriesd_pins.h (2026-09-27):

#pragma once
#include "sdkconfig.h"

// Bridge CONFIG_ flags to UM_BOARD_* so you can also -DUM_BOARD_xxx if preferred
#if defined(CONFIG_UM_BOARD_TINYS3D) && !defined(UM_BOARD_TINYS3D)
#define UM_BOARD_TINYS3D
#elif defined(CONFIG_UM_BOARD_FEATHERS3D) && !defined(UM_BOARD_FEATHERS3D)
#define UM_BOARD_FEATHERS3D
#elif defined(CONFIG_UM_BOARD_PROS3D) && !defined(UM_BOARD_PROS3D)
#define UM_BOARD_PROS3D
#elif defined(CONFIG_UM_BOARD_EDGES3D) && !defined(UM_BOARD_EDGES3D)
#define UM_BOARD_EDGES3D
#elif defined(CONFIG_UM_BOARD_TINYPICOD) && !defined(UM_BOARD_TINYPICOD)
#define UM_BOARD_TINYPICOD
#elif defined(CONFIG_UM_BOARD_TINYC6D) && !defined(UM_BOARD_TINYC6D)
#define UM_BOARD_TINYC6D
#endif

// ---------- Board-fixed pin maps (from the Arduino helper & board schematics) ----------
// -1 means the board doesn't have that feature
#if defined(UM_BOARD_TINYS3D)
#define UM_BOARD_NAME "TinyS3[D]"
#define UM_GPIO_PIXEL 18     // RGB_DATA
#define UM_GPIO_PIXEL_PWR 17 // RGB_PWR
#define UM_GPIO_LDO2 -1
#define UM_GPIO_VBUS_SENSE 33
#define UM_GPIO_BLUE_LED -1
#define UM_GPIO_RF_SWITCH 38 // High = external antenna
#define UM_GPIO_ALS -1
#define UM_GPIO_I2C_SDA 8
#define UM_GPIO_I2C_SCL 9

#elif defined(UM_BOARD_FEATHERS3D)
#define UM_BOARD_NAME "FeatherS3[D]"
#define UM_GPIO_PIXEL 40     // RGB_DATA
#define UM_GPIO_PIXEL_PWR 39 // RGB_PWR is LDO2
#define UM_GPIO_LDO2 39
#define UM_GPIO_VBUS_SENSE 34
#define UM_GPIO_BLUE_LED 13 // LED_BUILTIN
#define UM_GPIO_RF_SWITCH 41
#define UM_GPIO_ALS 4 // ALS on ADC1 (GPIO4)
#define UM_GPIO_I2C_SDA 8
#define UM_GPIO_I2C_SCL 9

#elif defined(UM_BOARD_PROS3D)
#define UM_BOARD_NAME "ProS3[D]"
#define UM_GPIO_PIXEL 18
#define UM_GPIO_PIXEL_PWR 17 // RGB_PWR is LDO2
#define UM_GPIO_LDO2 17
#define UM_GPIO_VBUS_SENSE 33
#define UM_GPIO_BLUE_LED -1
#define UM_GPIO_RF_SWITCH 11
#define UM_GPIO_ALS -1
#define UM_GPIO_I2C_SDA 8
#define UM_GPIO_I2C_SCL 9

#elif defined(UM_BOARD_EDGES3D)
#define UM_BOARD_NAME "EdgeS3[D]"
#define UM_GPIO_PIXEL -1
#define UM_GPIO_PIXEL_PWR -1
#define UM_GPIO_LDO2 -1
#define UM_GPIO_VBUS_SENSE -1
#define UM_GPIO_BLUE_LED -1
#define UM_GPIO_RF_SWITCH 38
#define UM_GPIO_ALS -1
#define UM_GPIO_I2C_SDA 8
#define UM_GPIO_I2C_SCL 9

#elif defined(UM_BOARD_TINYPICOD)
#define UM_BOARD_NAME "TinyPICO[D]"
#define UM_GPIO_PIXEL 2
#define UM_GPIO_PIXEL_PWR 13
#define UM_GPIO_LDO2 -1
#define UM_GPIO_VBUS_SENSE 9
#define UM_GPIO_BLUE_LED -1
#define UM_GPIO_RF_SWITCH 12
#define UM_GPIO_ALS -1
#define UM_GPIO_I2C_SDA 21
#define UM_GPIO_I2C_SCL 22

#elif defined(UM_BOARD_TINYC6D)
#define UM_BOARD_NAME "TinyC6[D]"
#define UM_GPIO_PIXEL 23
#define UM_GPIO_PIXEL_PWR 22
#define UM_GPIO_LDO2 -1
#define UM_GPIO_VBUS_SENSE 5
#define UM_GPIO_BLUE_LED -1
#define UM_GPIO_RF_SWITCH -1 // RF switch is on the IO expander
#define UM_GPIO_ALS -1
#define UM_GPIO_I2C_SDA 6
#define UM_GPIO_I2C_SCL 7
#define UM_HAS_IO_EXPANDER 1
#define UM_IOX_RF_SWITCH 0 // FXL6408 XIO0
#if defined(CONFIG_UM_IOX_I2C_ADDR)
#define UM_IOX_I2C_ADDR CONFIG_UM_IOX_I2C_ADDR
#else
#define UM_IOX_I2C_ADDR 0x43
#endif

#else
#error "No UM_BOARD_xxx defined. Select a board in menuconfig or pass -DUM_BOARD_TINYS3D (etc.)."
#endif

// Catch a board that doesn't match the IDF target (menuconfig already enforces this)
#if (defined(UM_BOARD_TINYS3D) || defined(UM_BOARD_FEATHERS3D) || defined(UM_BOARD_PROS3D) || defined(UM_BOARD_EDGES3D)) && !CONFIG_IDF_TARGET_ESP32S3
#error "This Series[D] board needs the esp32s3 target (idf.py set-target esp32s3)"
#elif defined(UM_BOARD_TINYPICOD) && !CONFIG_IDF_TARGET_ESP32
#error "TinyPICO[D] needs the esp32 target (idf.py set-target esp32)"
#elif defined(UM_BOARD_TINYC6D) && !CONFIG_IDF_TARGET_ESP32C6
#error "TinyC6[D] needs the esp32c6 target (idf.py set-target esp32c6)"
#endif

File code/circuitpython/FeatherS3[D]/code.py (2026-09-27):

# FeatherS3[D] Shipping Code
# 2025 Seon Rozenblum, Unexpected Maker
#
# Project home:
#   https://feathers3.io
#

import time, gc, os
import neopixel
import board, digitalio
import feathers3d

# Create a NeoPixel instance
# Brightness of 0.3 is ample for the 1515 sized LED
pixel = neopixel.NeoPixel(board.NEOPIXEL, 1, brightness=0.3, auto_write=True, pixel_order=neopixel.RGB)

# Say hello
print("\nHello from feathers3d!")
print("------------------\n")

# Show available memory
print("Memory Info - gc.mem_free()")
print("---------------------------")
print("{} Bytes\n".format(gc.mem_free()))

flash = os.statvfs('/')
flash_size = flash[0] * flash[2]
flash_free = flash[0] * flash[3]
# Show flash size
print("Flash - os.statvfs('/')")
print("---------------------------")
print("Size: {} Bytes\nFree: {} Bytes\n".format(flash_size, flash_free))

print("Pixel Time!\n")

# Create a colour wheel index int
color_index = 0

# Turn on the power to the NeoPixel
feathers3d.set_ldo2_power(True)

# Rainbow colours on the NeoPixel
while True:
    # Get the R,G,B values of the next colour
    r,g,b = feathers3d.rgb_color_wheel( color_index )
    # Set the colour on the NeoPixel
    pixel[0] = ( r, g, b, 0.5)
    # Increase the wheel index
    color_index += 1

    # If the index == 255, loop it
    if color_index == 255:
        color_index = 0
        # Invert the internal LED state every half colour cycle
        feathers3d.led_blink()
        
    # Sleep for 15ms so the colour cycle isn't too fast
    time.sleep(0.015)
    
